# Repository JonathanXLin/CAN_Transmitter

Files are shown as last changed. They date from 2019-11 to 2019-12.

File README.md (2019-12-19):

# CAN_Transmitter

<br>
<p align="center"> 
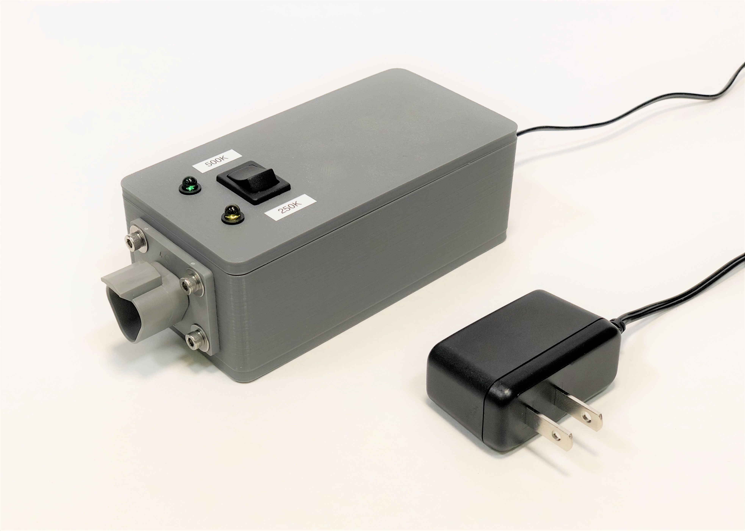
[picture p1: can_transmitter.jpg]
  
</p>
<br>

Please read the User Guide for more information.

This CAN transmitter sends cyclic CAN messages for automotive products undergoing long duration testing. This is intended to be easy to create, program, and configure. The following are user configurable:
<br><br>•	Baud rate
<br>•	CAN ID type (11/29 bit)
<br>•	Number of CAN messages
  <br>&nbsp;&nbsp;&nbsp;o	CAN message IDs
  <br>&nbsp;&nbsp;&nbsp;o	CAN message DLCs
  <br>&nbsp;&nbsp;&nbsp;o	CAN message data
  <br>&nbsp;&nbsp;&nbsp;o	CAN message period
<br><br>
  
In addition, rev2 code adds the capability of data logging. Incoming CAN frames are stored in a plain ASCII file (.txt). Due to hardware limitations, if the incoming message frequency exceeds 30Hz, bad things will happen (CAN buffer overflow and log file becomes inaccurate, IRQ handler hogs processor time and transmit messages don't get transmitted).

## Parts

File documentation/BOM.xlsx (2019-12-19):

Description | Manufacturer Part # | Qty | Price | Extended Price | In-House
ARDUINO UNO SMD R3 ATMEGA328 | A000073 | 1 | $20.90 | $20.90
CANBUS SHIELD V2 | 103030215 | 1 | $24.50 | $24.50
LED Panel Mount Indicators 5mm Grn | PM5GT | 1 | $0.69 | $0.69
LED Panel Mount Indicators Blue 430nm | PM5BWC | 1 | $1.40 | $1.40
SWITCH ROCKER DPDT 16A 125V | GRS-4022-1600 | 1 | $1.38 | $1.38
CONN RCPT HSG 3POS | DT04-3P-L012 | 1 | $4.35 | $4.35 | Yes
CONN PIN 14AWG NICKEL CRIMP | 0460-215-16141 | 1 | $0.63 | $0.63 | Yes
18-8 Stainless Steel Socket Cap Screw | 73412 | 4 | - | - | Yes
#4 F/W S/S .125x.312 | 71004 | 4 | - | - | Yes
4-40 S/S MS Nut | 1170704 | 4 | - | - | Yes
RES 100 OHM 1/4W 5% AXIAL | CF14JT100R | 1 | $0.10 | $0.10 | Yes
AC/DC WALL MOUNT ADAPTER 9V 5W | VEL05US090-US-JA | 1 | $6.50 | $6.50
FLEX RLTF 7 BLK w/3165 NUT | 3464 | 1 | $1.17 | $1.17
Mounting Hardware 0.5x.14" Rubber Feet | 1421T2GY | 1 | $6.48 | $6.48
USB CABLE TYPE A TO B 30CM BLACK | Seeed Technology | 1 | $1.99 | $1.99 | Yes
 |  |  | Total: | $70.09

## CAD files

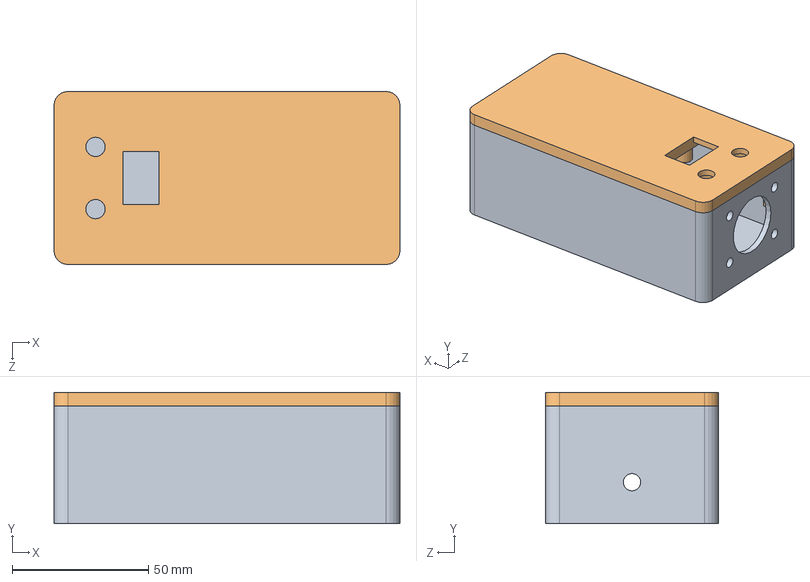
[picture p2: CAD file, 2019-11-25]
models/v2/sldprt/CAN_Transmitter_Assembly.SLDASM
127.0 x 48.3 x 63.5 mm
CAN_Transmitter_Enclosure
CAN_Transmitter_Lid

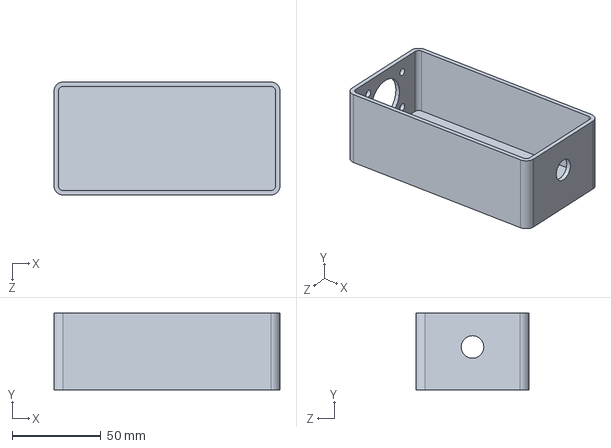
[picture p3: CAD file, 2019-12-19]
models/v2/sldprt/CAN_Transmitter_Enclosure.SLDPRT
127.0 x 43.2 x 63.5 mm

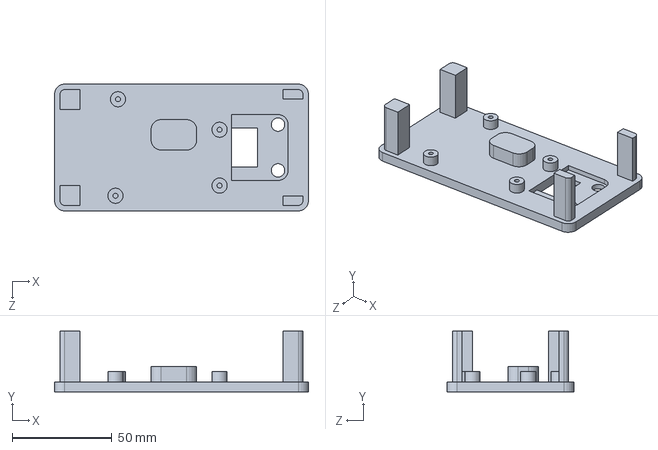
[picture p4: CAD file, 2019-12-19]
models/v2/sldprt/CAN_Transmitter_Lid.SLDPRT
127.0 x 30.5 x 63.5 mm

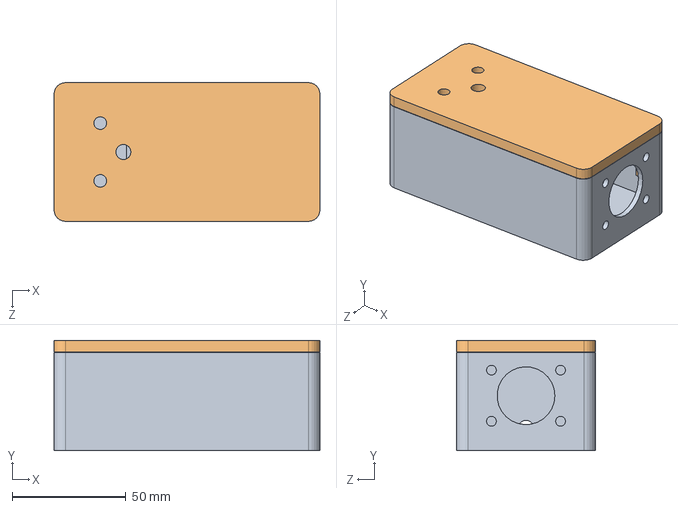
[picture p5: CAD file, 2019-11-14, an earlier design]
models/v1/sldprt/CAN_Transmitter_Assembly.SLDASM
116.8 x 48.4 x 61.0 mm
Memerator_Enclosure
Memerator_Lid

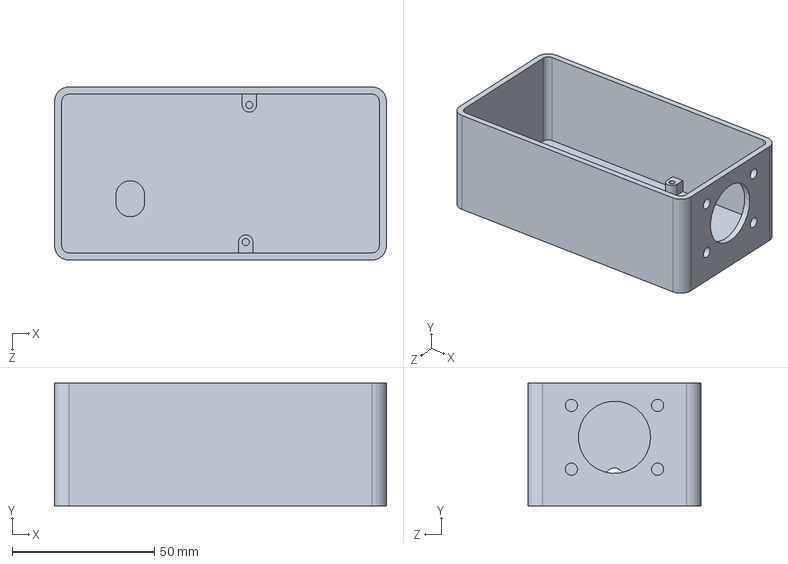
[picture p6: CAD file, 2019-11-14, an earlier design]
models/v1/sldprt/CAN_Transmitter_Enclosure.SLDPRT
116.8 x 43.2 x 61.0 mm

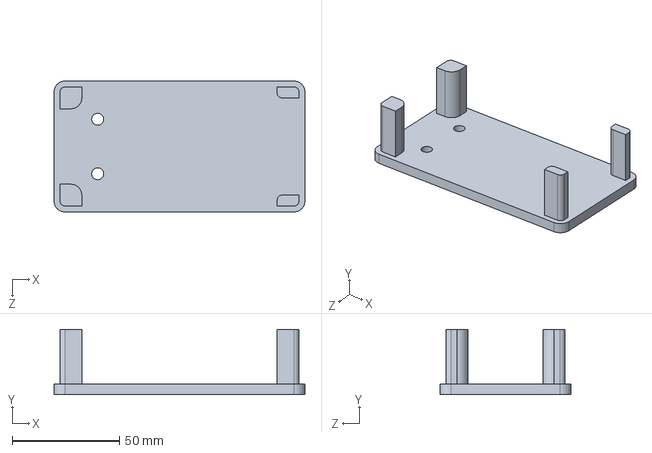
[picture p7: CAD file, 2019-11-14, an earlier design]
models/v1/sldprt/CAN_Transmitter_Lid.SLDPRT
116.8 x 30.5 x 61.0 mm

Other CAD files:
models/v1/stl/CAN_Transmitter_Enclosure.STL
models/v1/stl/CAN_Transmitter_Lid.STL
models/v2/stl/CAN_Transmitter_Enclosure.STL
models/v2/stl/CAN_Transmitter_Lid.STL

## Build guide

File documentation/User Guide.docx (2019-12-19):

# CAN Transmitter User Guide

# 1 Overview

This CAN transmitter sends cyclic CAN messages required by DECUs undergoing testing. This CAN transmitter is intended to be easy to create, easy to program, and easy to configure. The user can configure the following parameters:

- Baud rate
- CAN ID type (11/29 bit)
- Number of CAN messages
  - CAN message IDs
  - CAN message DLCs
  - CAN message data
  - CAN message period

This project is and requires software licensed under the MIT License, which permits commercial use, modification, and distribution. Additional details are provided under Licensing and Disclaimer.

All files and future updates for this project can be found in the following repository:

https://github.com/JonathanXLin/CAN_Transmitter

# 2 Required Files and BOM

## 2.1 BOM

The CAN transmitter is based off the Arduino Uno development board and the Seeed Technology CAN BUS shield. Minor and optional materials, such as solder and heat shrink tubing, are not included.

Table 1: CAN Transmitter BOM

Description | Manufacturer Part # | Qty | Price | Extended Price | In-House
ARDUINO UNO SMD R3 ATMEGA328 | A000073 | 1 | $ 20.90 | $ 20.90
CANBUS SHIELD V2 | 103030215 | 1 | $ 24.50 | $ 24.50
LED Panel Mount Indicators 5mm Grn | PM5GT | 1 | $ 0.69 | $ 0.69
LED Panel Mount Indicators Blue 430nm | PM5BWC | 1 | $ 1.40 | $ 1.40
SWITCH ROCKER DPDT 16A 125V | GRS-4022-1600 | 1 | $ 1.38 | $ 1.38
CONN RCPT HSG 3POS | DT04-3P-L012 | 1 | $ 4.35 | $ 4.35 | Yes
CONN PIN 14AWG NICKEL CRIMP | 0460-215-16141 | 1 | $ 0.63 | $ 0.63 | Yes
18-8 Stainless Steel Socket Cap Screw | 73412 | 4 | - | - | Yes
#4 F/W S/S .125x.312 | 71004 | 4 | - | - | Yes

4-40 S/S MS Nut | 1170704 | 4 | - | - | Yes
RES 100 OHM 1/4W 5% AXIAL | CF14JT100R | 1 | $ 0.10 | $ 0.10 | Yes
AC/DC WALL MOUNT ADAPTER 9V 5W | VEL05US090-US-JA | 1 | $ 6.50 | $ 6.50
FLEX RLTF 7 BLK w/3165 NUT | 3464 | 1 | $ 1.17 | $ 1.17
Mounting Hardware 0.5x.14" Rubber Feet | 1421T2GY | 1 | $ 6.48 | $ 6.48
USB CABLE TYPE A TO B 30CM BLACK | Seeed Technology | 1 | $ 1.99 | $ 1.99 | Yes
| | | Total: | $ 70.09

## 2.2 Enclosure Models

The CAN transmitter requires a box and lid. These two .stl files are to be 3D printed.

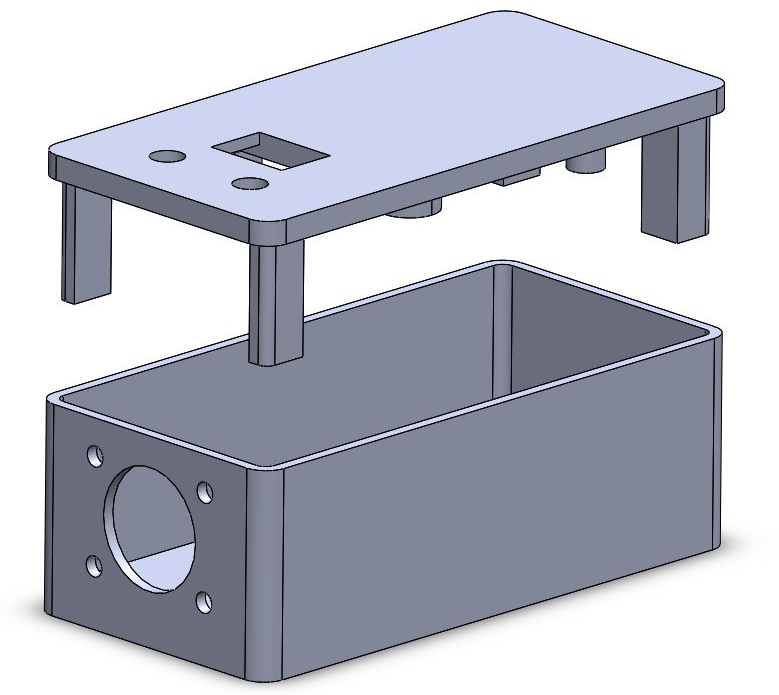
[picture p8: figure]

Figure 1: Enclosure Exploded View

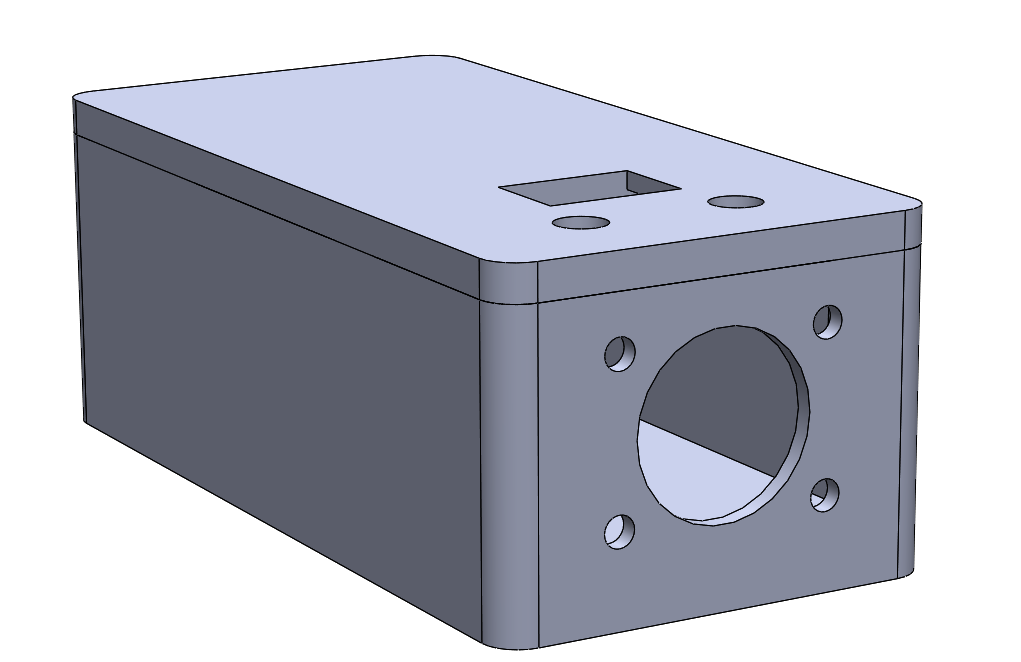
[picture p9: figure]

Figure 2: Enclosure Assembled View

## 2.3 Arduino Sketch

The CAN transmitter uses the Arduino sketch CAN_Transmitter.ino and the mcp_can library.

Figure 3: Required Files

# 3 Construction

## 3.1 Panel Mount Components

The Deutsch 3 pin connector is mounted on the front face using the bolt, washer, and nut as shown.

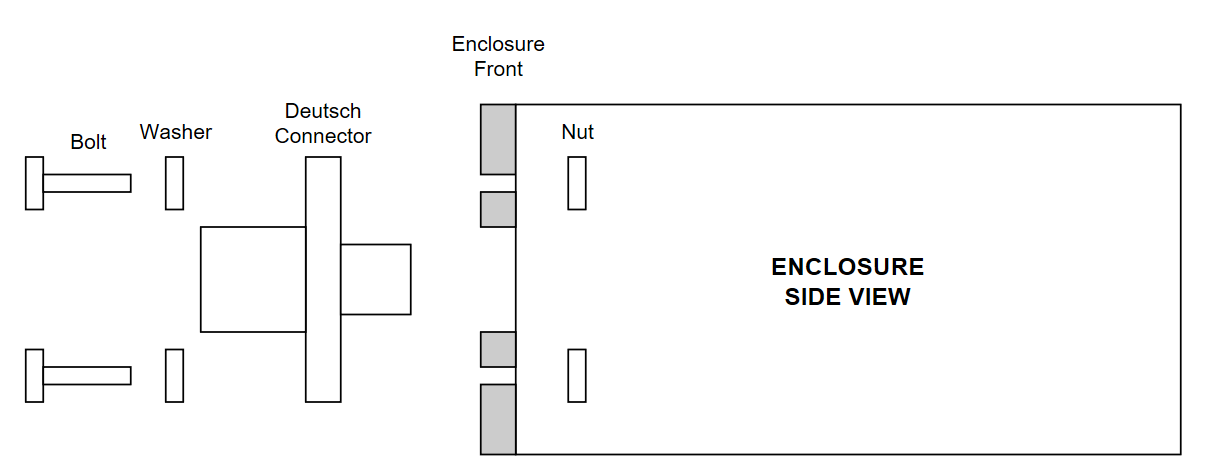
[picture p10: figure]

Figure 4: Enclosure Panel Mounted Components Side View

The indicator LEDs and switch are snap fitted into the lid cutouts. Pin 1 of the switch is farthest back from the orientation shown below. the LED arrangement does not matter. The CAN shield is attached to the Arduino, and the electronics assembly is screwed into the lid as shown below. It is recommended to label the switch “250kbs” and “500kbs”.

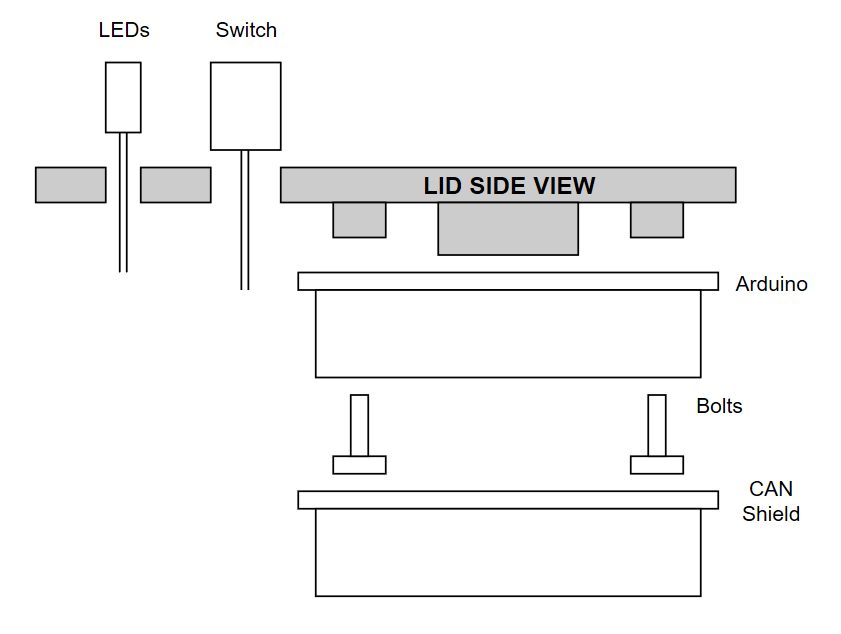
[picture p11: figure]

Figure 5: Lid Panel Mounted Components Side View

The power supply cable is cut to bare wire and pushed through the small hole at the back of the enclosure. Optionally, a ¼” grommet can be used. It is recommended to tightly knot the wire or use another form of strain relief to protect the solder joints from mechanical stress.

## 3.2 Electrical Connections

The following electrical connections are made. All connections are soldered except for the Deutsch pins, which are crimped.

Components to be Joined | | Notes
Deutsch Pin A | CAN Shield CAN H | Deutsch pin crimped and snap fit into connector
Deutsch Pin B | CAN Shield CAN L | Deutsch pin crimped and snap fit into connector
Power VIN | Arduino VIN
Power GND | Arduino GND
LED Green Cathode | Arduino Pin D7 | Add 100 Ω resistor in series
LED Green Anode | Arduino GND
LED Yellow Cathode | Arduino Pin D6 | Add 100 Ω resistor in series
LED Yellow Anode | Arduino GND
Switch Pin 1 | Arduino Pin D8
Switch Pin 2 | Arduino +5V | Optionally add 100 Ω resistor in series
Switch Pin 3 | Arduino Pin D9

## 3.3 Photos

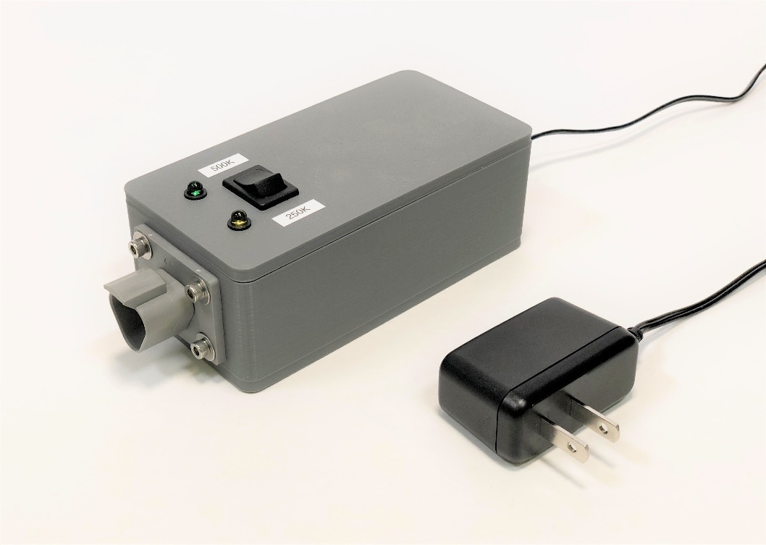
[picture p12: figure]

Figure 6: Complete CAN Transmitter

# 4 Environment Setup

## 4.1 Install Arduino IDE

Download and run the Windows Installer from the link below.

https://www.arduino.cc/en/Main/Software

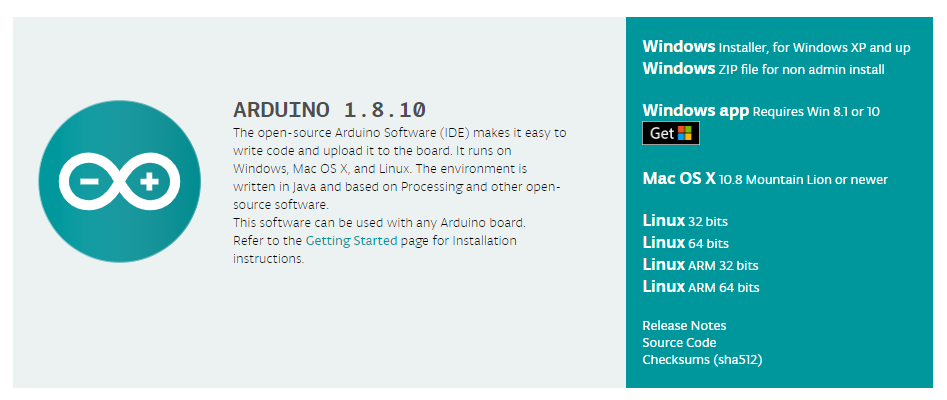
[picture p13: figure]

## 4.2 Install mcp_can Library

Download the mcp_can library by clicking Clone or Download, and Download ZIP from the link below.

https://github.com/coryjfowler/MCP_CAN_lib

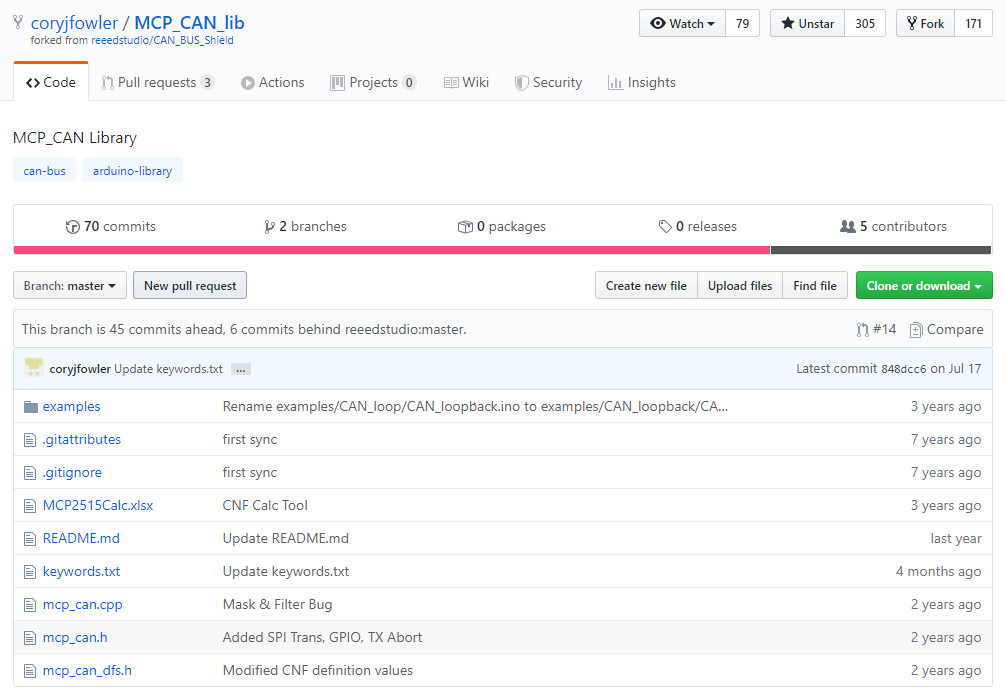
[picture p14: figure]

To install, open CAN_Transmitter.ino, navigate to Sketch » Include Library » Add .ZIP Library…, and add the downloaded .zip files.

# 5 Configuration and Programming

Open CAN_Transmitter.ino, ensuring it is in the folder with “can_cyclic.cpp” and “can_cyclic.hpp”.

The example above sends the CCVS1 and EBC2 messages with a period of 100ms each. To add a new cyclic CAN message, follow the same format with a new byte name and CAN_message_cyclic name.

To program, connect your PC to the Arduino with a USB A Male to USB B Male connector. Under Tools, ensure Board is selected as “Arduino/Genuino Uno”, and Port is selected as “(Arduino/Genuino Uno)”.

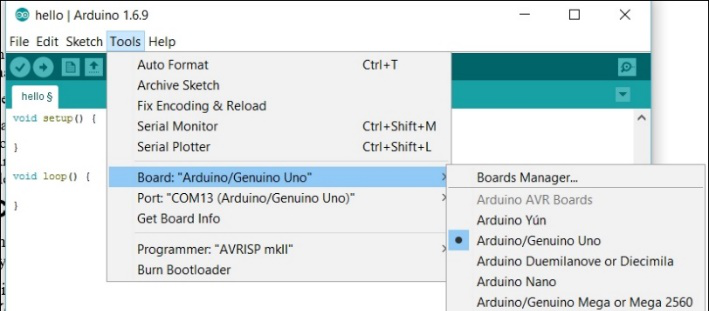
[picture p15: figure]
Image result for arduino genuino uno programming menu

In the top left corner, click the “Upload” button, and wait for the “Done Uploading” message to appear.

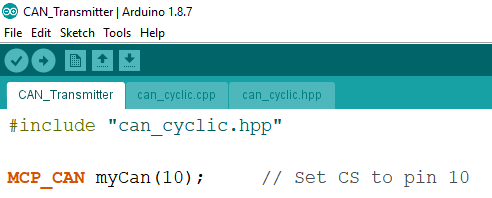
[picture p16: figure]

# 6 Use

Plug in the wall adapter. Both LEDs will blink, the Power LED will light, and CAN messages will be sent. The Signal LED will blink every time a sent message is acknowledged.

To switch baud rate, flip the switch. The change will immediately take into effect.

If there is an error initializing the CAN transceiver, both LEDs will continue blinking.

# 7 Licensing and Disclaimer

## 7.1 CAN Transmitter

The MIT License (MIT)

Copyright (c) 2019 Jonathan Lin

Permission is hereby granted, free of charge, to any person obtaining a copy

of this software and associated documentation files (the "Software"), to deal

in the Software without restriction, including without limitation the rights

to use, copy, modify, merge, publish, distribute, sublicense, and/or sell

copies of the Software, and to permit persons to whom the Software is

furnished to do so, subject to the following conditions:

The above copyright notice and this permission notice shall be included in

all copies or substantial portions of the Software.

THE SOFTWARE IS PROVIDED "AS IS", WITHOUT WARRANTY OF ANY KIND, EXPRESS OR

IMPLIED, INCLUDING BUT NOT LIMITED TO THE WARRANTIES OF MERCHANTABILITY,

FITNESS FOR A PARTICULAR PURPOSE AND NONINFRINGEMENT. IN NO EVENT SHALL THE

AUTHORS OR COPYRIGHT HOLDERS BE LIABLE FOR ANY CLAIM, DAMAGES OR OTHER

LIABILITY, WHETHER IN AN ACTION OF CONTRACT, TORT OR OTHERWISE, ARISING FROM,

OUT OF OR IN CONNECTION WITH THE SOFTWARE OR THE USE OR OTHER DEALINGS IN

THE SOFTWARE.

## 7.2 mcp_can Library

The MIT License (MIT)

Copyright (c) 2013 Seeed Technology Inc.

Permission is hereby granted, free of charge, to any person obtaining a copy

of this software and associated documentation files (the "Software"), to deal

in the Software without restriction, including without limitation the rights

to use, copy, modify, merge, publish, distribute, sublicense, and/or sell

copies of the Software, and to permit persons to whom the Software is

furnished to do so, subject to the following conditions:

The above copyright notice and this permission notice shall be included in

all copies or substantial portions of the Software.

THE SOFTWARE IS PROVIDED "AS IS", WITHOUT WARRANTY OF ANY KIND, EXPRESS OR

IMPLIED, INCLUDING BUT NOT LIMITED TO THE WARRANTIES OF MERCHANTABILITY,

FITNESS FOR A PARTICULAR PURPOSE AND NONINFRINGEMENT. IN NO EVENT SHALL THE

AUTHORS OR COPYRIGHT HOLDERS BE LIABLE FOR ANY CLAIM, DAMAGES OR OTHER

LIABILITY, WHETHER IN AN ACTION OF CONTRACT, TORT OR OTHERWISE, ARISING FROM,

OUT OF OR IN CONNECTION WITH THE SOFTWARE OR THE USE OR OTHER DEALINGS IN

THE SOFTWARE.

Jonathan Lin, Thomas Paraschuk Nov. 24, 2019

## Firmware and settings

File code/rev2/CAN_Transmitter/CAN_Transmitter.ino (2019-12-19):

#include "can_cyclic.hpp"

// =================================== TRANSMIT LIST =================================================
// byte your_data_name[8] = {your_data};
// CAN_message_cyclic CCVS1(your_address, your_dlc, your_data_name, your_period);

byte CCVS1_data[8] = {0x37, 0x00, 0x00, 0xCF, 0x3F, 0xFF, 0xFF, 0xFF};
CAN_message_cyclic CCVS1(0x18FEF100, 8, CCVS1_data, 100);

byte EBC2_data[8] = {0x00, 0x00, 0x00, 0x00, 0x00, 0x00, 0x00, 0x00};
CAN_message_cyclic EBC2(0x18FEBF0B, 8, EBC2_data, 100);
// ===================================================================================================

void setup(){
  // Initializes CAN and LEDs
  CAN_initialize();
  SD_initialize();
}

void loop(){
  // One line for each CAN message
  CCVS1.send_CAN();
  EBC2.send_CAN();

  print_can_receive();
}

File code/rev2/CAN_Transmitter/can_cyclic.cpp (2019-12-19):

#include "can_cyclic.hpp"

MCP_CAN myCan(9);     // Set CS to pin 9

unsigned char flagRecv = 0;
unsigned char len = 0;
unsigned char buf[8];
char str[20];

unsigned long message_count = 0; // Message number sent/received

void CAN_initialize() {
  pinMode(led_pwr, OUTPUT);
  pinMode(led_tx, OUTPUT);
  pinMode(pin_baud_select, INPUT);

  digitalWrite(led_pwr, LOW);
  digitalWrite(led_tx, LOW);

  Serial.begin(9600);

  if (digitalRead(pin_baud_select))
  {
    // Initialize MCP2515 running at 16MHz with a baudrate of 250kb/s and the masks and filters disabled.
    if (myCan.begin(CAN_250KBPS) == CAN_OK)
      Serial.println("MCP2515 250KBPS Initialized Successfully!");
    else
    {
      while (1)
      {
        Serial.println("Error Initializing MCP2515 250KBPS...");

        digitalWrite(led_pwr, HIGH);
        delay(300);
        digitalWrite(led_pwr, LOW);
        delay(300);
      }
    }
  }
  else
  {
    // Initialize MCP2515 running at 16MHz with a baudrate of 500kb/s and the masks and filters disabled.
    if (myCan.begin(CAN_500KBPS) == CAN_OK)
      Serial.println("MCP2515 500KBPS Initialized Successfully!");
    else
    {
      while (1)
      {
        Serial.println("Error Initializing MCP2515 500KBPS...");

        digitalWrite(led_pwr, HIGH);
        delay(300);
        digitalWrite(led_pwr, LOW);
        delay(300);
      }
    }
  }

  attachInterrupt(0, MCP2515_ISR, FALLING); // start interrupt

  digitalWrite(led_pwr, HIGH);
}

CAN_message_cyclic::CAN_message_cyclic(long can_id, int can_dlc, byte *can_data, int can_period) {
  id = can_id;
  dlc = can_dlc;

  for (int i = 0; i < 8; i++)
  {
    data[i] = can_data[i];
  }

  period = can_period;
  millis_next = millis() + period;

  led_millis_next = 999999999999; // Initialize to large so LED functions will not run when no CAN message has transmitted
  led_flag = false;

  pin_baud_select_prev = digitalRead(pin_baud_select);
}

void CAN_message_cyclic::send_CAN() {
  if (millis() > millis_next)
  {
    // send data:  ID = 0x100, Standard CAN Frame, Data length = 8 bytes, 'data' = array of data bytes to send
    byte sndStat = 0;

    int pin_baud_select_curr = digitalRead(pin_baud_select);
    if (pin_baud_select_curr != pin_baud_select_prev)
    {
      if (pin_baud_select_curr)
      {
        // Initialize MCP2515 running at 16MHz with a baudrate of 250kb/s and the masks and filters disabled.
        if (myCan.begin(CAN_250KBPS) == CAN_OK)
          Serial.println("MCP2515 250KBPS Initialized Successfully!");
        else
        {
          while (1)
          {
            Serial.println("Error Initializing MCP2515 250KBPS...");

            digitalWrite(led_pwr, HIGH);
            delay(300);
            digitalWrite(led_pwr, LOW);
            delay(300);
          }
        }

        attachInterrupt(0, MCP2515_ISR, FALLING); // start interrupt
      }
      else
      {
        // Initialize MCP2515 running at 16MHz with a baudrate of 500kb/s and the masks and filters disabled.
        if (myCan.begin(CAN_500KBPS) == CAN_OK)
          Serial.println("MCP2515 500KBPS Initialized Successfully!");
        else
        {
          while (1)
          {
            Serial.println("Error Initializing MCP2515 500KBPS...");

            digitalWrite(led_pwr, HIGH);
            delay(300);
            digitalWrite(led_pwr, LOW);
            delay(300);
          }
        }

        attachInterrupt(0, MCP2515_ISR, FALLING); // start interrupt
      }
    }
    pin_baud_select_prev = pin_baud_select_curr;

    sndStat = myCan.sendMsgBuf(id, CAN_ID_29_BIT, dlc, data);;

    if (sndStat == CAN_OK)
    {
      //Serial.print("SENT AND RECEIVED, message id: ");
      //Serial.print(id, HEX);
      //Serial.println();
    }
    else
    {
      //Serial.print("ERROR SENDING MESSAGE, message id: ");
      //Serial.print(id, HEX);
      //Serial.println();
    }

    millis_next = millis() + period; // Update millis_next

    if (!led_flag)
    {
      digitalWrite(led_tx, HIGH);
      led_flag = true;
    }

    led_millis_next = millis() + 50; // Update led_millis_next
  }

  if (millis() > led_millis_next && led_flag)
  {
    digitalWrite(led_tx, LOW);
    led_flag = false;
  }
}

void SD_initialize() {
  if (!SD.begin(4))
  {
    SERIAL.println("SD initialization failed!");
    while (1);
  }
  SERIAL.println("SD initialization done.");

  File myFile = SD.open("test.txt", FILE_WRITE);
  myFile.println("test");
  myFile.close();
}

void MCP2515_ISR() {
  flagRecv = 1;
}

void print_can_receive() {
  if (flagRecv)
  { // check if get data
    flagRecv = 0;                   // clear flag
    unsigned long id = 0;

    // iterate over all pending messages
    // If either the bus is saturated or the MCU is busy,
    // both RX buffers may be in use and reading a single
    // message does not clear the IRQ conditon.
    while (myCan.checkReceive() == CAN_MSGAVAIL)
    {
      // read data,  len: data length, buf: data buf
      myCan.readMsgBufID(&id, &len, buf);

      /*
      Serial.print(((double)millis()) / 1000.0);
      Serial.print(" ");
      Serial.print("1");
      Serial.print("  ");
      Serial.print(id);
      Serial.print("x");
      Serial.print("  ");
      Serial.print("Rx");
      Serial.print("            ");
      Serial.print(len);
      Serial.print(" ");

      for (int i = 0; i < len; i++)
      {
        Serial.print(buf[i]);
        Serial.print(" ");
      }

      Serial.print("            ");
      Serial.print(message_count);
      Serial.println();
      */

      File myFile = SD.open("test.txt", FILE_WRITE);
      
      String message_log = "";
      
      message_log += String(((double)millis())/1000.0);
      message_log += " ";
      message_log += "1";
      message_log += "  ";
      message_log += String(id);
      message_log += "x";
      message_log += "  ";
      message_log += "Rx";
      message_log += "            ";
      message_log += String(len);
      message_log += " ";

      for (int i = 0; i < len; i++)
      {
        message_log += String(buf[i], HEX);
        message_log += " ";
      }

      message_log += "            ";
      message_log += String(message_count);
      
      myFile.println(message_log);
      myFile.close();

      message_count++;
    }
  }
}

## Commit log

2019-11-13 Initial models
    [Memerator_Assembly.SLDASM, Memerator_Enclosure.SLDPRT, Memerator_Enclosure.STL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]
2019-11-14 updated stl
    [Memerator_Assembly.SLDASM, Memerator_Enclosure.STL, Memerator_Lid.SLDPRT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]
2019-11-14 Added BOM and User Guide
    [BOM.xlsx]
2019-11-14 Model update
    [Memerator_Enclosure.SLDPRT, Memerator_Enclosure.STL, Memerator_Lid.SLDPRT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]
2019-11-22 update bom
    [BOM.xlsx]
2019-11-22 Added diagrams and updated BOM
    [BOM.xlsx]
2019-11-24 Final update for baud rate switch
2019-11-25 document edit diagrams
    [CAN_Transmitter_Assembly.SLDASM, CAN_Transmitter_Enclosure.SLDPRT, CAN_Transmitter_Enclosure.STL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]
2019-12-05 init rev3 code, add CAN receive
    [CAN_Transmitter_Lid.SLDPRT, CAN_Transmitter_Lid.STL]
2019-12-06 update bom and add photos
2019-12-12 update led logic
